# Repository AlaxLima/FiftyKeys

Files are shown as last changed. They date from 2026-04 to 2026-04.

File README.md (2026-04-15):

# FiftyKeys
A personal documentation of my from-scratch handwired 50-key keyboard design.

FiftyKeys

This project has been done back in **May 2025**. However, I have made the decision to publish this project as of April 2026.
The name FiftyKeys was chosen because this keyboard has exactly 50 keys, which had several design choices in mind that will be described further.

#### Note about licensing: 
This project is only for personal showcase, and is licensed under the [Creative Commons BY-NC-ND 4.0 License](https://github.com/AlaxLima/FiftyKeys/blob/main/LICENSE.txt).

Commercial use and redistribution of modified or works are strictly prohibited. See usage terms below for details.

### A personal goal achieved for this project
FiftyKeys does not use flashed **QMK** firmware. Yes, this keyboard is **fully programmed using Arduino C++**, and still mimics features like scanning speed adjustment, layer switching, macro mapping.

## Keyboard layout
Originally, I have decided to design a true minimal 40% layout, which only features the alpha cluster and several basic modifiers on the bottom row. However, after a while using a replica of an open-source project that featured such layout - the [Tanuki 40%](https://github.com/SethSenpai/Tanuki) by [SethSenpai](https://github.com/SethSenpai), the heavy use of layer shifting key combos eventually showed its constraints from a person who came from 65% boards.
Therefore, to maintain the minimalism of not having the number row, but keep certain areas reachable, the standard layout of this keyboard adopted:
- A standard 6.25U spacebar
- [HKKB](https://happyhackingkb.com/)-style bottom corners
- Fully accessible arrow cluster
- Delete key next to Enter/Backspace (Inspired by the Filco Majestouch Minila Air) (image different from personal adjustments)
- 3 modifers of Win, Ctrl and Shift all present
- Play/Pause media key

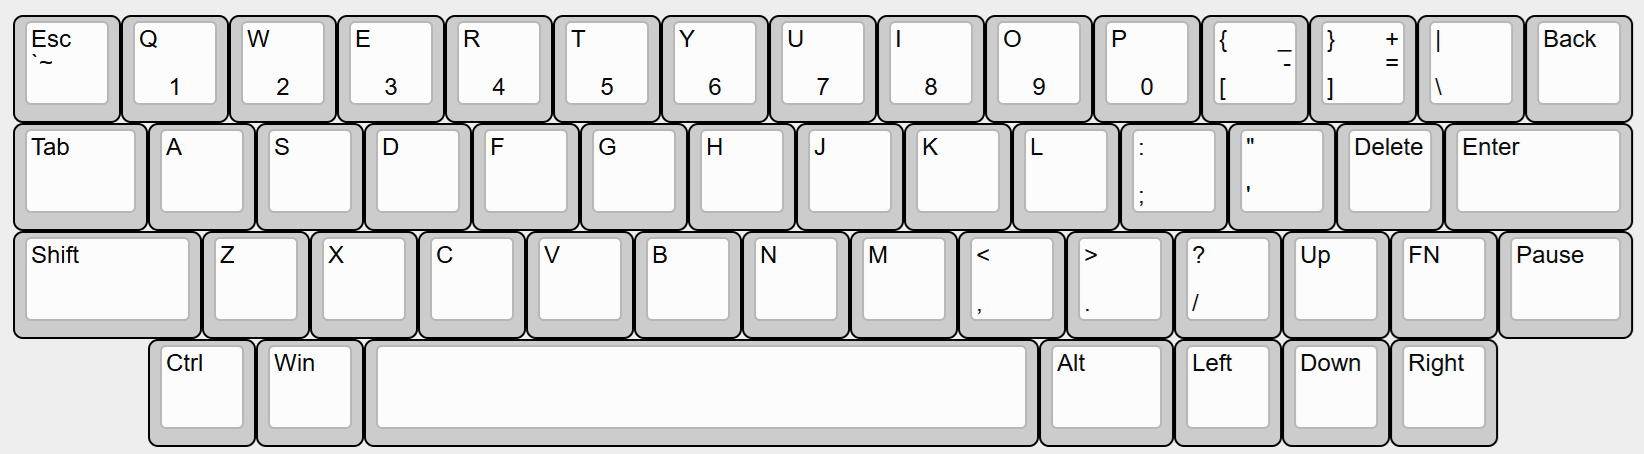
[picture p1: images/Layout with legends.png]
Layout


## Case and matrix design

### Plate and Case

While sandwich-design boards are easier and simpler to design, having a solid piece of plastic bottom case and a thick top bezel is my personal preference. Therefore, based on the original key size from KLE, further perimeter is added to work on the bezel and screw holes (via QCAD and FreeCAD).

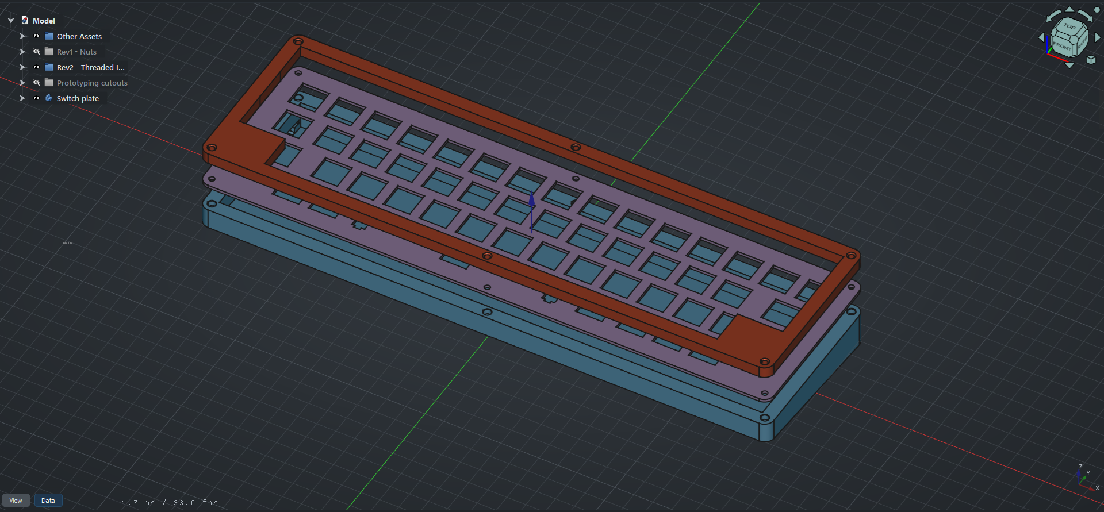
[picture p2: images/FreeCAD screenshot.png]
FreeCAD screenshot


Even though the plate is also modelled here, it is meant for a lasercutting for a 1.5mm aluminium plate (or Inox/Steel, any sheet metal material that can provide adequate rigidity).
Assembly uses M3 heat-threaded inserts inside the 3D printed bottom case, and installed with countersunk M3 screws

### Matrix circuitry

Like many other handwired projects, FiftyKeys uses an Arduino Pro Micro on a handwired matrix. On this matrix, all rows and columns are mapped out from A to F and 1 to 9, which later corresponds to the pins on the microcontroller. The rows are chained with 1N4148 diodes (basic anti-ghosting component for keyboards), while gauge wire are used for columns, and further soft wires to the microcontroller.

Handrawn matrix to reference to during solder, keymapping and pin mapping in code:
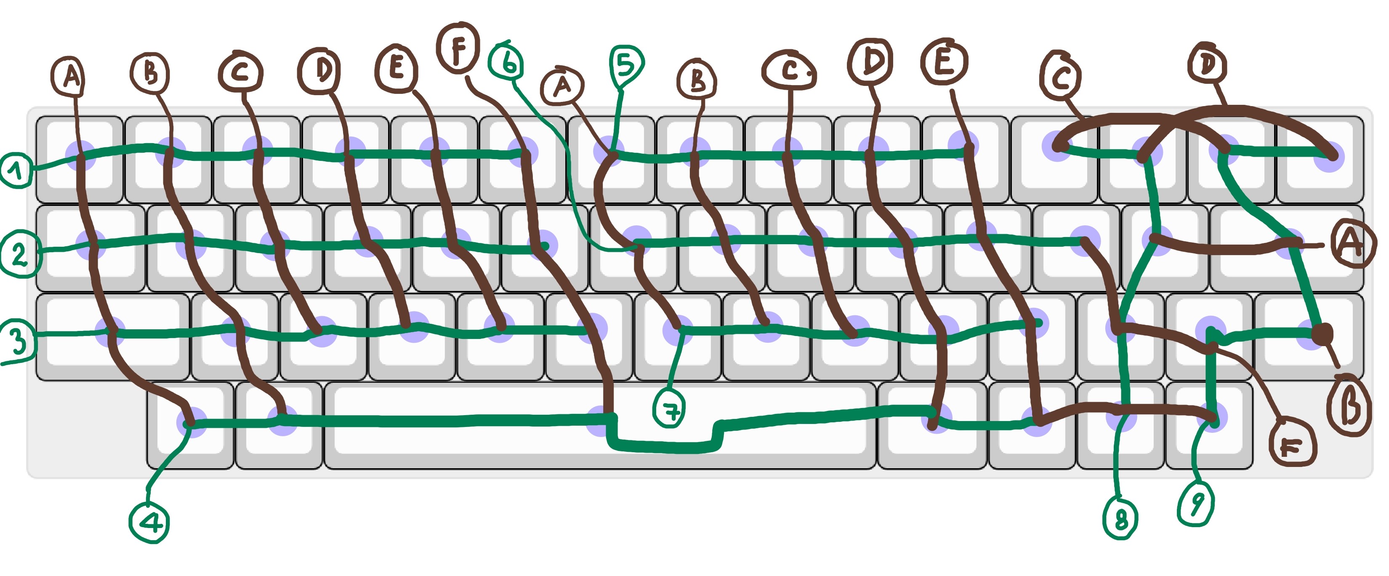
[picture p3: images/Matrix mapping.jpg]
Matrix mapping


Since I do not have SMD solder experience, I had to use a pin breakout board instead for a pigtail cable. Therefore, the acoustic foam mod for the keyboard requires a cutout solely for the bulky part of the microcontroller and the pigtail board itself. In addition, the Elaina sticker is in the center to prevent the microcontroller's flashing light getting through the PETG plastic's 3D print.

Interior1 image

### Arduino code

This project's personally hardest part lies in the big number one goal at the start: It needs to be an entire code structure that at least does certain basic things that QMK does out of the box. However, another personal wanting was made during back during the making: To intentionally add a certain level of modularity to the code so that it can later be easily fixed, or reused for any future personal projects (which is clearly a low likelihood).

There is a sheer amount of repetitiveness and certain choices made that could have been improved (which gave birth to the idea of a .h file to focus more on the complex part instead of the repetitive part), but any further development was stopped to prevent personal scope creep.

If you would like to view the code and understand further how it works, the [.ino code file](https://github.com/AlaxLima/FiftyKeys/blob/main/code/FiftyKeys_Firmware.ino) and its [lookup .h file](https://github.com/AlaxLima/FiftyKeys/blob/main/code/KeyLookupSwitch.h) is available in this repository. A snippet of temporary troubleshooter code was also included, which you can see it as a snapshot of my work half-done during then.

Still, to have a brief showcase, here is a TL;DR tree structure simplified using my own language:

```
Keyboard codebase (.ino file, uploaded via Arduino IDE)
├── Keymapping
│   └── Which key to map on all keys in every layer
├── Direct Port Control macro setup
│   └── Simplify all port manipulation codes into functions
├── Timer1 Interrupt
│   └── Initial setup
├── void setup()
│   └── Arduino configuration for pins and libraries
├── Matrix reading
│   ├── Logic to read through columns per driven row
│   │   ├── Keycode lookup (keycode, keytype and layer)
│   │   └── Press and release management
│   └── Logic loop
├── Sleep mechanism
│   ├── Secondary tick for sleep modes
│   └── Adjust Timer1 by sleep status
└── Macro Engine
    └── MacroMap interpreter
Offset file (.h file, included inside the codebase)
├── Filter between macro/consumer/keyboard keys and press/release state
│   ├── Keyboard.h keys lookup
│   ├── Consumer.h keys lookup
│   └── Macro keys lookup
└── Macro array configuration
```

### Usage terms regarding license restrictions

This project and documentation is made as a personal showcase of my own work in keyboard design and microcontroller code development. It is open to non-commercial use, which includes:
- Reference, learning from the code and design
- Create personal replicas
However, the following uses are not permitted:
- Commercial use or production of any of the project's material
- Redistribution of derivative or modified works
- Use any material in this project in other projects intended for distribution
- Reposting/republishing of any content from this repository elsewhere

Re-implementation is allowed, however it must not be direct use of any assets. Feel free to contact me for any use beyond these terms.

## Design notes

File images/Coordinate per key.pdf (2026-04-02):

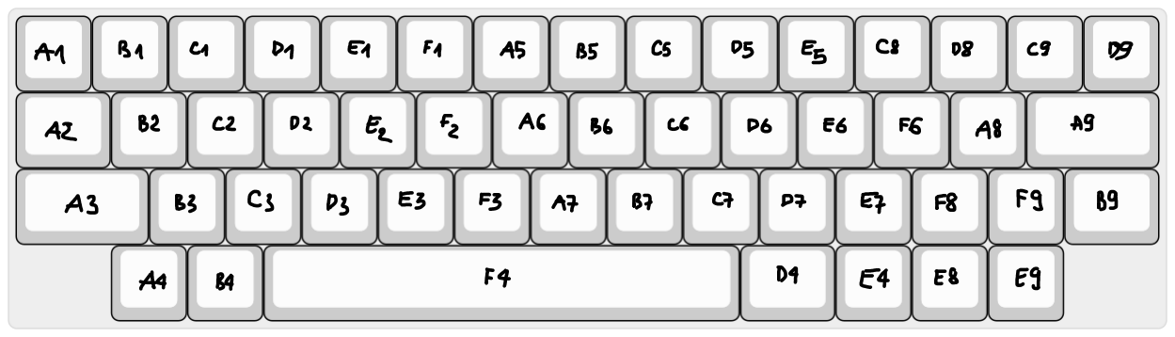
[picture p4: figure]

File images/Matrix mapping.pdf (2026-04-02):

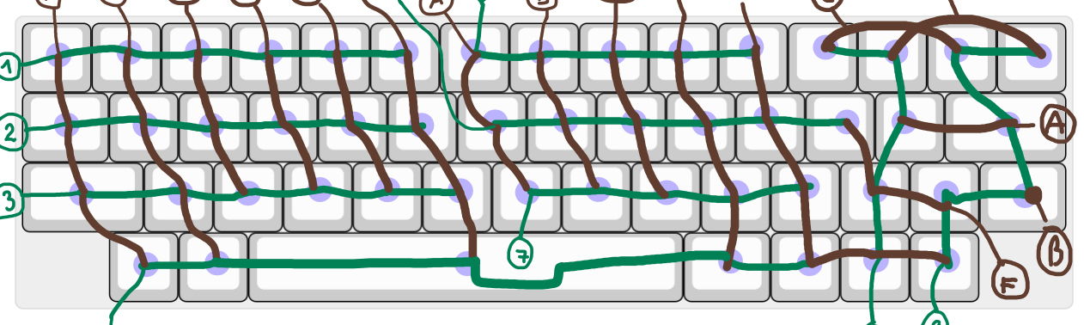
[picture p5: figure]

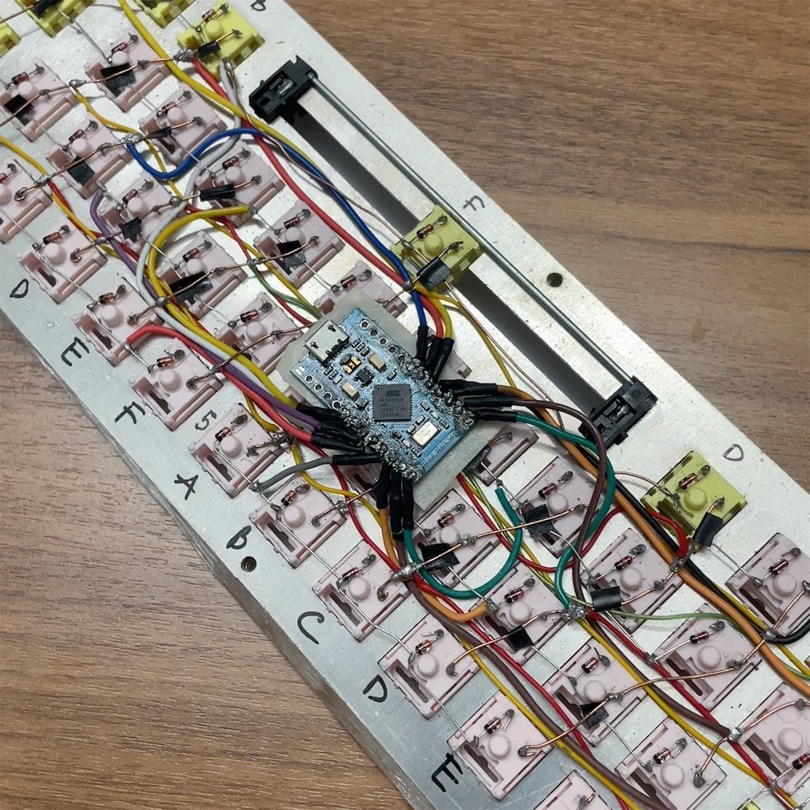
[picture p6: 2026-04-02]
images/Interior2.png

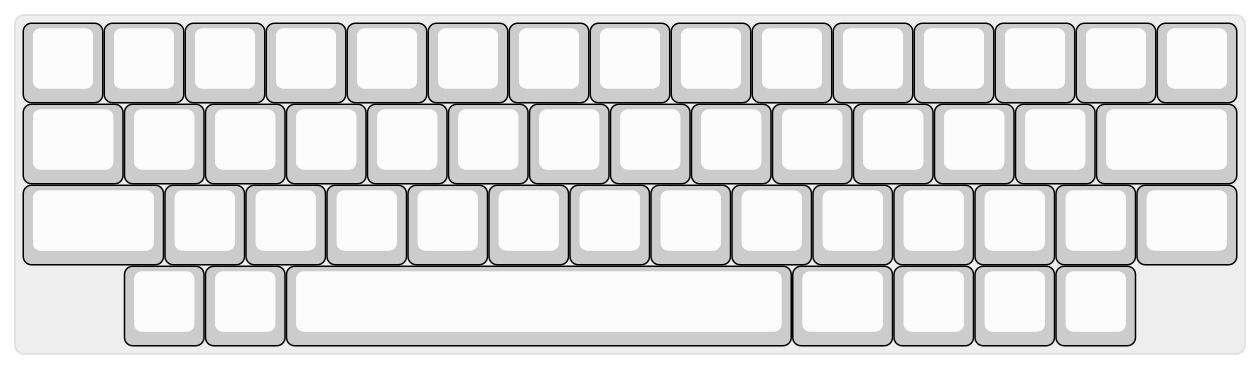
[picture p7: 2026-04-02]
images/Layout blank.png

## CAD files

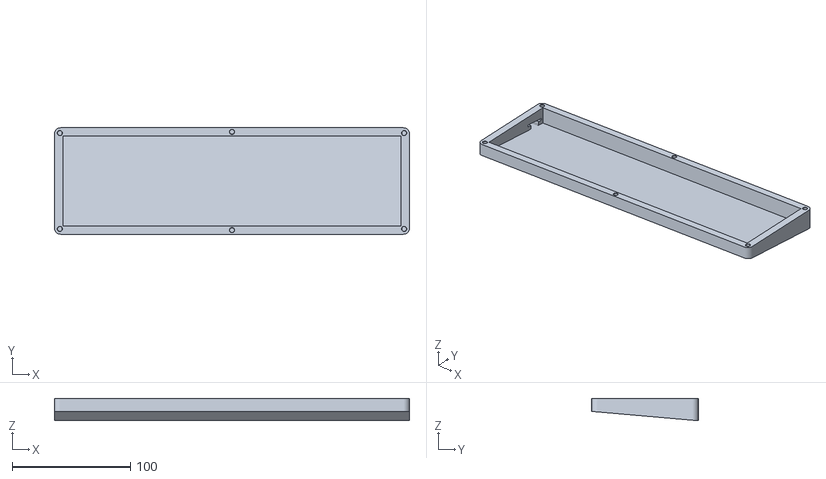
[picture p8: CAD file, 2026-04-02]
designs/FiftyKeys-Case.stl
300.0 x 90.0 x 19.0

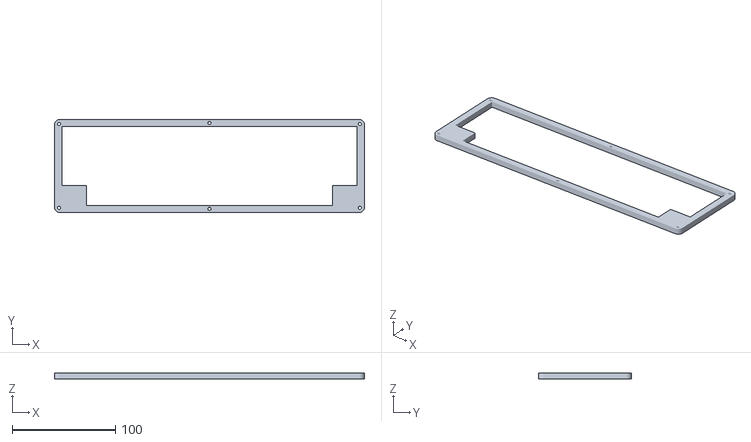
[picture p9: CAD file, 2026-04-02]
designs/FiftyKeys-Bezel.stl
300.0 x 90.0 x 6.00

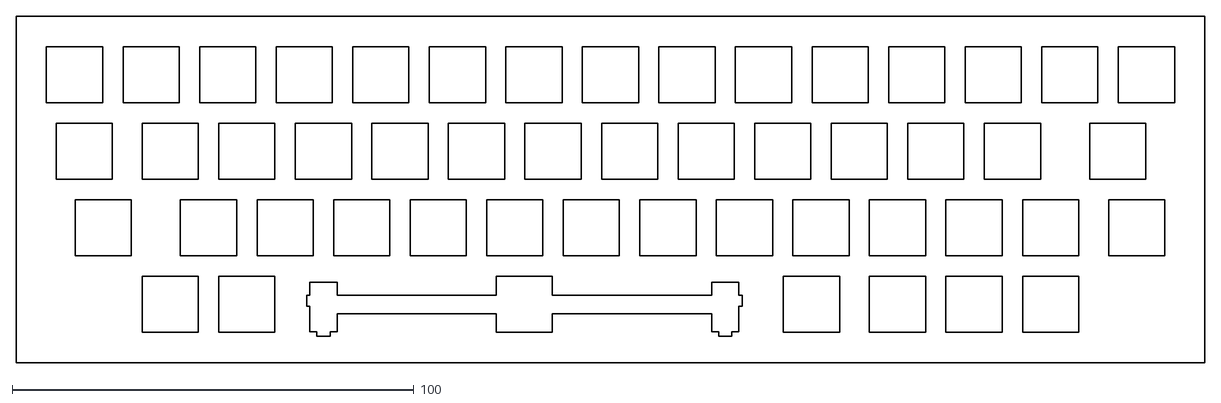
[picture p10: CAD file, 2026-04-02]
designs/Keebio Plate Gen export from KLE.dxf
295.7 x 86.2

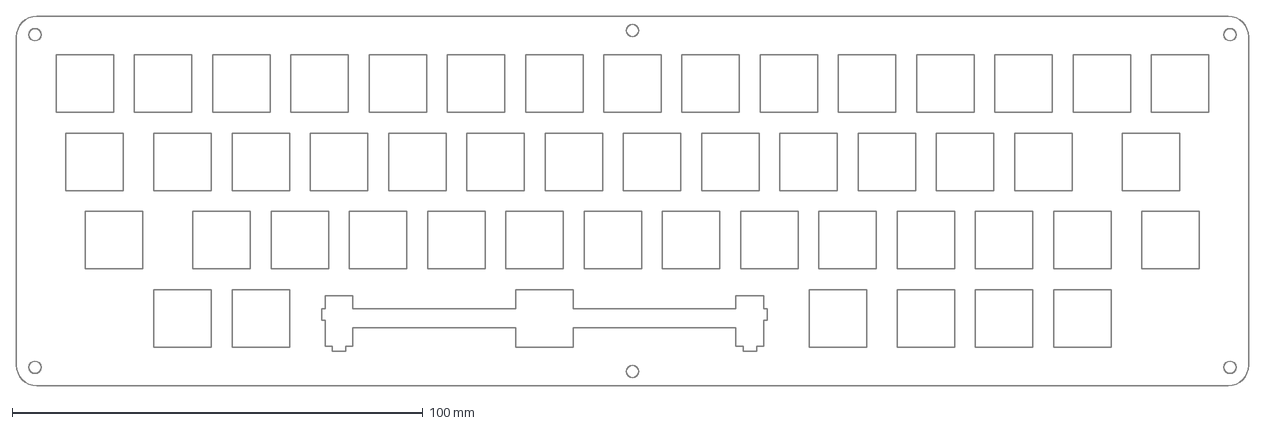
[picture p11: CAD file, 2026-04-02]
designs/Keyplate - lasercut ver.dxf
300.0 x 90.0 mm

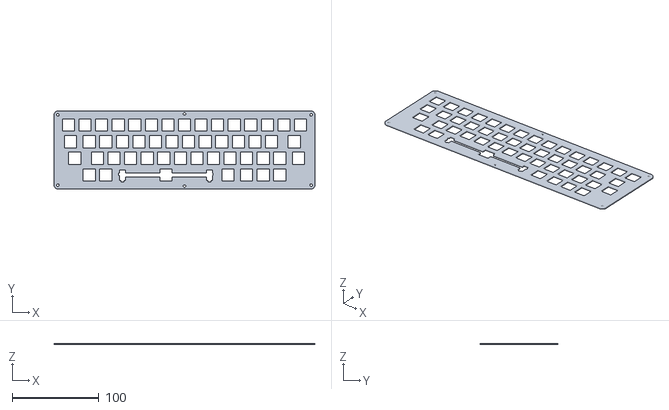
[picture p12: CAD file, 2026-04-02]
designs/FiftyKeys-Plate.stl
300.0 x 90.0 x 1.60

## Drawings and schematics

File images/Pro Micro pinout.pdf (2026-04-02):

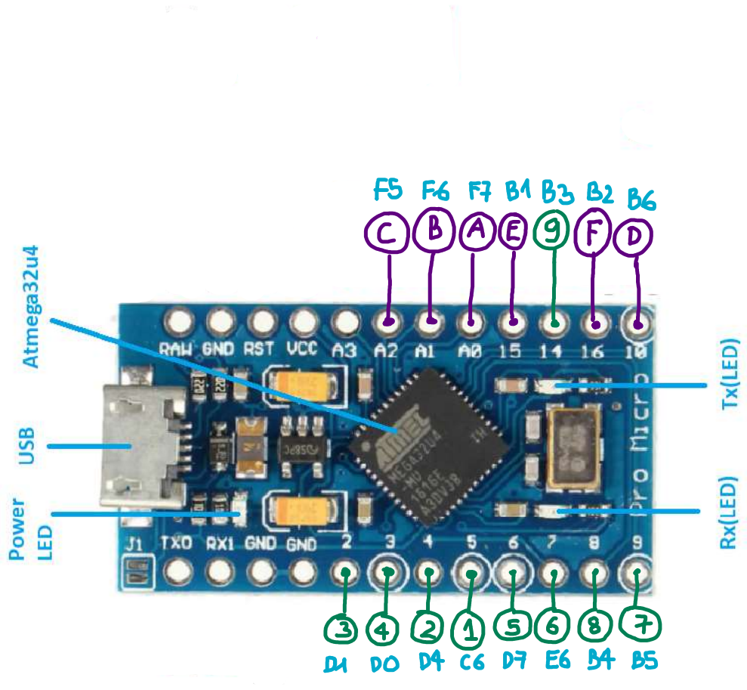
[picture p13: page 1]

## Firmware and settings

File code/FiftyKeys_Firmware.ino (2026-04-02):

#include <HID-Project.h>
#include <HID-Settings.h>

#include "KeyLookupSwitch.h"
// #include "BoardConf.h"

/*
// 2 parallel arrays in flash
#define ENTRY(name, code) const char name##_str[] PROGMEM = #name;
KEY_LIST
#undef ENTRY

struct KeyPair { const char* str; uint8_t code; };

#define ENTRY(name, code) { name##_str, code },
const KeyPair keyTable[] PROGMEM = {
  KEY_LIST
};
#undef ENTRY


// Runtime string converter
const uint8_t keyCount = sizeof(keyTable) / sizeof(keyTable[0]);

uint8_t resolveKey(const char* alias) {
  for (uint8_t i = 0; i < keyCount; i++) {
    const char* p = (const char*)pgm_read_ptr(&keyTable[i].str);
    if (strcmp_P(alias, p) == 0) {
      return pgm_read_byte(&keyTable[i].code);
    }
  }
  return 0;                // fall-back “no key”
}
*/

// #define NO_KEY 0x00 // KEY_RESERVED is a predefined option instead of this
const uint8_t KEY_FUNCTION = 255; // Custom FN key to be used for other purposes, max value of uint8_t is 255
const uint8_t KEY_REMAPPED_LEFT_ALT = 50;

const uint8_t MACRO_01 = 235;
const uint8_t MACRO_02 = 236;
const uint8_t MACRO_03 = 237;
const uint8_t MACRO_04 = 238;
const uint8_t MACRO_05 = 239;
const uint8_t MACRO_06 = 240;
const uint8_t MACRO_07 = 241;
const uint8_t MACRO_08 = 242;
const uint8_t MACRO_09 = 243;
const uint8_t MACRO_10 = 244;

const uint8_t layerCount = 2;
const uint8_t rowCount = 9;
const uint8_t columnCount = 6;

bool keyStates[rowCount][columnCount] = {false}; // Row-major key state matrix

const uint8_t KeyMap[layerCount][rowCount][columnCount] = {
    {{KEY_ESC, KEY_Q, KEY_W, KEY_E, KEY_R, KEY_T},
     {KEY_TAB, KEY_A, KEY_S, KEY_D, KEY_F, KEY_G},
     {KEY_LEFT_SHIFT, KEY_Z, KEY_X, KEY_C, KEY_V, KEY_B},
     {KEY_LEFT_CTRL, KEY_LEFT_GUI, KEY_RESERVED, KEY_REMAPPED_LEFT_ALT, KEY_LEFT_ARROW, KEY_SPACE},
     {KEY_Y, KEY_U, KEY_I, KEY_O, KEY_P, KEY_RESERVED},
     {KEY_H, KEY_J, KEY_K, KEY_L, KEY_SEMICOLON, KEY_QUOTE},
     {KEY_N, KEY_M, KEY_COMMA, KEY_PERIOD, KEY_SLASH, KEY_RESERVED},
     {KEY_BACKSLASH, KEY_RESERVED, KEY_LEFT_BRACE, KEY_RIGHT_BRACE, KEY_DOWN_ARROW, KEY_UP_ARROW},
     {KEY_ENTER, MEDIA_PLAY_PAUSE, KEY_BACKSPACE, KEY_DELETE, KEY_RIGHT_ARROW, KEY_FUNCTION}},
    {{KEY_TILDE, KEY_1, KEY_2, KEY_3, KEY_4, KEY_5},
     {KEY_CAPS_LOCK, KEY_F1, KEY_F3, KEY_F5, KEY_F7, KEY_F9},
     {KEY_LEFT_SHIFT, KEY_F2, KEY_F4, KEY_F6, KEY_F8, KEY_F10},
     {KEY_LEFT_CTRL, KEY_LEFT_GUI, KEY_RESERVED, KEY_RIGHT_ALT, MEDIA_PREVIOUS, MEDIA_VOLUME_MUTE},
     {KEY_6, KEY_7, KEY_8, KEY_9, KEY_0, KEY_RESERVED},
     {KEY_F11, KEY_RESERVED, KEY_RESERVED, MACRO_03, MACRO_05, MACRO_06},
     {KEY_F12, MACRO_02, CONSUMER_BRIGHTNESS_DOWN, CONSUMER_BRIGHTNESS_UP, KEY_INSERT, KEY_RESERVED},
     {KEY_DELETE, KEY_RESERVED, KEY_MINUS, KEY_EQUAL, MEDIA_VOLUME_DOWN, MEDIA_VOLUME_UP},
     {KEY_ENTER, MEDIA_VOLUME_MUTE, KEY_RESERVED, MACRO_04, MEDIA_NEXT, KEY_FUNCTION}}};

/*
const uint8_t L1KeyMapRow0[6] = {KEY_ESC, KEY_Q, KEY_W, KEY_E, KEY_R, KEY_T};
const uint8_t L1KeyMapRow1[6] = {KEY_TAB, KEY_A, KEY_S, KEY_D, KEY_F, KEY_G};
const uint8_t L1KeyMapRow2[6] = {KEY_LEFT_SHIFT, KEY_Z, KEY_X, KEY_C, KEY_V, KEY_B};
const uint8_t L1KeyMapRow3[6] = {KEY_LEFT_CTRL, KEY_LEFT_GUI, KEY_RESERVED, KEY_RIGHT_ALT, KEY_LEFT_ARROW, KEY_SPACE};
const uint8_t L1KeyMapRow4[6] = {KEY_Y, KEY_U, KEY_I, KEY_O, KEY_P, KEY_RESERVED};
const uint8_t L1KeyMapRow5[6] = {KEY_H, KEY_J, KEY_K, KEY_L, KEY_SEMICOLON, KEY_QUOTE};
const uint8_t L1KeyMapRow6[6] = {KEY_N, KEY_M, KEY_COMMA, KEY_PERIOD, KEY_SLASH, KEY_RESERVED};
const uint8_t L1KeyMapRow7[6] = {KEY_DELETE, KEY_RESERVED, KEY_LEFT_BRACE, KEY_RIGHT_BRACE, KEY_DOWN_ARROW, KEY_UP_ARROW};
const uint8_t L1KeyMapRow8[6] = {KEY_ENTER, MEDIA_PLAY_PAUSE, KEY_BACKSPACE, KEY_BACKSLASH, KEY_RIGHT_ARROW, KEY_FUNCTION};

const uint8_t *L1KeyMap[9] = {
    L1KeyMapRow0,
    L1KeyMapRow1,
    L1KeyMapRow2,
    L1KeyMapRow3,
    L1KeyMapRow4,
    L1KeyMapRow5,
    L1KeyMapRow6,
    L1KeyMapRow7,
    L1KeyMapRow8,
};
*/

uint8_t layer = 0; // For global FN key, overwrite capability
bool activeFlag = 1;

// -- Macros for Direct Port Control --

// Predessor macros that did not worked with the arrays
// #define DirectHIGH(port, pin) (PORT##port |= (1 << pin))
// #define DirectLOW(port, pin) ((PORT##port) &= ~(1 << (pin)))

// This is more likely preferred
#define SetLow(reg, bit) (*(reg) &= ~(1 << (bit)))
#define SetHigh(reg, bit) (*(reg) |= (1 << (bit)))

// One inline macro
// Active-low because INPUT_PULLUP
#define PullupRead(idx) (!(*(colPortRegs[idx]) & _BV(colBits[idx])))

// Keyboard pinout
// Direct port:       C6 D4 D1 D0 D7 E6 B5 B4 B1
uint8_t rowPins[9] = {5, 4, 2, 3, 6, 7, 9, 8, 14};
uint8_t colPins[6] = {A0, A1, A2, 10, 15, 16};

// Row pin port pointers
volatile uint8_t *const rowPortRegs[9] = {
    &PORTC, &PORTD, &PORTD, &PORTD, &PORTD, &PORTE, &PORTB, &PORTB, &PORTB};
const uint8_t rowBits[9] = {6, 4, 1, 0, 7, 6, 5, 4, 3};

volatile uint8_t *const colPortRegs[6] = {
    &PINF, &PINF, &PINF, &PINB, &PINB, &PINB};
const uint8_t colBits[6] = {7, 6, 5, 6, 1, 2};

// TimerInterrupt initalize
void initialTimer1()
{
    cli(); // Disable interrupts
    TCCR1A = 0;
    TCCR1B = 0;
    TCCR1B |= (1 << WGM12);              // CTC mode
    TCCR1B |= (1 << CS11) | (1 << CS10); // Prescaler 64
    OCR1A = 999;                         // (16MHz / 64 / Hz) - 1
    TIMSK1 |= (1 << OCIE1A);             // Enable compare interrupt

    // !!!! DO NOT DELETE OR BOARD WILL CORRUPT !!!!
    sei(); // Enable interrupts
}

void setup()
{
    // Initialize ISR modules
    initialTimer1();

    Serial.begin(9600);

    // Rows initialization
    for (int r = 0; r < 9; r++)
    {
        pinMode(rowPins[r], OUTPUT);
        digitalWrite(rowPins[r], HIGH);
    }

    // Columns initialization
    for (int c = 0; c < 6; c++)
    {
        pinMode(colPins[c], INPUT_PULLUP);
        // digitalWrite(colPins[c], HIGH); //No need for conventional pinMode declaration
    }
    // Keyboard.begin();
    Consumer.begin();
    // currentLayer = 1;
}

void coordinateDiagnostics(bool keyState, uint8_t outputRow, uint8_t outputCol, uint8_t outputKeycode)
{
    switch (keyState)
    {
    case 1:
        Serial.println("");
        Serial.println("[PRESSING]");
        Serial.print("Row ");
        Serial.print(outputRow);
        Serial.print(" column ");
        Serial.print(outputCol);
        Serial.print(" - Keycode ");
        Serial.println(outputKeycode);
        break;
    case 0:
        Serial.println("");
        Serial.println("[RELEASING]");
        Serial.print("Row ");
        Serial.print(outputRow);
        Serial.print(" column ");
        Serial.print(outputCol);
        Serial.print(" - Keycode ");
        Serial.println(outputKeycode);
        break;
    }
}

uint8_t layerSwitch(uint8_t keycode)
{
    switch (keycode)
    {
    case 255:
        return 2;
        break;
    default:
        return 1;
        break;
    }
}
/*
void readingRow0()
{
    for (int c = 0; c < 6; c++)
    {
        bool colRead = PullupRead(c); // = 1 when pressed
        // const char *alias = L1KeyMapRow1[c];
        // uint8_t code = resolveKey(alias);

        if (colRead && !keyStates[0][c]) // was not pressed before
        {
            keyStates[0][c] = true;
            keyTypeLookup(1, L1KeyMap[0][c]);
            coordinateDiagnostics(keyStates[0][c], 0, c, L1KeyMap[0][c]);
        }
        else if (!colRead && keyStates[0][c]) // was pressed, now released
        {
            keyTypeLookup(0, L1KeyMap[0][c]);
            keyStates[0][c] = false;
            coordinateDiagnostics(keyStates[0][c], 0, c, L1KeyMap[0][c]);
        }
    }
}
*/

/*
void readingRows(uint8_t row) // First try
{
    for (int c = 0; c < 6; c++)
    {
        bool colRead = PullupRead(c); // = 1 when pressed
        // const char *alias = L1KeyMapRow1[c];
        // uint8_t code = resolveKey(alias);

        if (colRead && !keyStates[row][c]) // was not pressed before
        {
            keyStates[row][c] = true;
            keyTypeLookup(1, L1KeyMap[row][c]);
            coordinateDiagnostics(keyStates[row][c], 0, c, L1KeyMap[row][c]);
        }
        else if (!colRead && keyStates[row][c]) // was pressed, now released
        {
            keyTypeLookup(0, L1KeyMap[row][c]);
            coordinateDiagnostics(keyStates[row][c], 1, c, L1KeyMap[row][c]);
            break;
            keyStates[row][c] = false;
        }
    }
}
*/

void readingRows(uint8_t row)
{
    for (int col = 0; col < columnCount; col++)
    {
        bool colRead = PullupRead(col); // active low
        uint8_t key = KeyMap[layer][row][col];

        if (key == KEY_RESERVED)
            continue;

        if (colRead && !keyStates[row][col])
        {
            keyStates[row][col] = true;
            activeFlag = 1;

            if (key == KEY_FUNCTION)
            {
                layer = 1;
                Keyboard.releaseAll();
            }
            else if (isMacroKeycode(key))
            {
                MacroRun(key);
            }
            else
            {
                keyTypeLookup(1, key);
            }
            // coordinateDiagnostics(keyStates[row][col], row, col, key);
        }
        else if (!colRead && keyStates[row][col])
        {
            keyStates[row][col] = false;
            activeFlag = 0;

            if (key == KEY_FUNCTION)
            {
                layer = 0;
                Keyboard.releaseAll();
            }
            else if (!isMacroKeycode(key)) // Don't "release" macro
            {
                keyTypeLookup(0, key);
            }
            // coordinateDiagnostics(keyStates[row][col], row, col, key);
        }
    }
}

// Column reading
void chosenReadingRow(uint8_t activeRow)
{
    /*
    switch (activeRow)
    {
    case 0:
        readingRows(0);
        break;
    case 1:
        readingRows(1);
        break;
    case 2:
        readingRows(2);
        break;
    case 3:
        readingRows(3);
        break;
    case 4:
        readingRows(4);
        break;
    case 5:
        readingRows(5);
        break;
    case 6:
        readingRows(6);
        break;
    case 7:
        readingRows(7);
        break;
    case 8:
        readingRows(activeRow);
        break;
    }
    */
    readingRows(activeRow);

    /*

    for (int c = 0; c < 6; c++)
    {
        bool colRead = PullupRead(c); // true = key is pressed

        // const char *alias = L1KeyMapRow1[c];
        // uint8_t code = resolveKey(alias);

        if (colRead && !keyStates[0][c]) // was not pressed before
        {
            //Keyboard.press(code); // replace with your key map later
            keyStates[activeRow][c] = true;
            keyborePress(L1KeyMap[activeRow][c]);
            Serial.print("Pressed row ");
            Serial.print(activeRow);
            Serial.print(" column ");
            Serial.println(c);
        }
        else if (!colRead && keyStates[0][c]) // was pressed, now released
        {
            keyboreRelease(L1KeyMap[activeRow][c]);
            keyStates[activeRow][c] = false;
            Serial.print("Released row ");
            Serial.print(activeRow);
            Serial.print(" column ");
            Serial.println(c);
            Serial.print("Key code is ");
            Serial.println(L1KeyMap[activeRow][c]);
        }
    }
    */
}

inline void driveRow(uint8_t activeRow)
{
    for (uint8_t r = 0; r < 9; r++)
    {
        if (r == activeRow)
            SetLow(rowPortRegs[r], rowBits[r]); // selected row LOW
        else
            SetHigh(rowPortRegs[r], rowBits[r]); // others HIGH
    }
}

ISR(TIMER1_COMPA_vect)
{
    static uint8_t row = 0;
    driveRow(row); // set the lines
    // chosenReadingRow(row); // read ONLY ONCE
    readingRows(row);
    row = (row + 1) % 9; // next row next tick
}

/* ─── VOID LOOP USED FOR IDLING COUNT ─── */
void adjustTimer1(int status, uint16_t OCR1A_tickrate)
{
    switch (status)
    {
    case -1:
        cli(); // Disable interrupts
        TCCR1B |= (1 << CS11) | (1 << CS10);
        TIMSK1 |= (1 << OCIE1A);
        OCR1A = OCR1A_tickrate;
        sei(); // Enable interrupts
        break;
    case 1:
        cli();
        OCR1A = OCR1A_tickrate;
        TCCR1B &= ~(1 << CS10); // Clear CS10
        TCCR1B &= ~(1 << CS11); // Clear CS11
        TCCR1B &= ~(1 << CS12); // Clear CS12
        TIMSK1 &= ~(1 << OCIE1A);
        sei();
        break;
    case 0:
        cli();
        OCR1A = OCR1A_tickrate;
        sei();
        break;
    }

    /*
    Adjustments:
    - Shutdown:     1 + 62499
    - Startup:      -1 + ACTIVE mode value
    - Change:       0 + IDLE mode value
    */
}

const uint16_t SLEEP_TIMEOUT = 100;

uint8_t ACTIVE_RATE = 499;
uint8_t SLEEP_RATE = 62499; // No need anyway

bool sleepLock = 0;
bool openAllRows = 0;

void loop()
{
    while (!sleepLock)
    {
        for (uint16_t t = 0; t < SLEEP_TIMEOUT + 1; t++)
        {
            if (activeFlag)
            {
                // Serial.println("Hewoo :3");
                // adjustTimer1(0, ACTIVE_RATE);
                break;
            }
            switch (t)
            {
            case SLEEP_TIMEOUT:
                adjustTimer1(1, SLEEP_RATE);
                Serial.println("--zzz--zzz-");
                sleepLock = 1;
                openAllRows = 1;
            default:
                break;
            }
            // Serial.println();
            delay(100);
        }
    }
    while (sleepLock)
    {
        if (openAllRows)
        {
            for (uint8_t r = 0; r < rowCount; r++)
            {
                SetLow(rowPortRegs[r], rowBits[r]);
            }
            openAllRows = 0;
        }
        uint8_t sumCol = PullupRead(0) + PullupRead(1) + PullupRead(2) + PullupRead(3) + PullupRead(4) + PullupRead(5);
        if (sumCol > 0)
        {
            adjustTimer1(-1, ACTIVE_RATE);
            Serial.println("Good meowning~ nya~ :3");
            activeFlag = 1;
            sleepLock = 0; // Wake the board up
            break;
        }
        delay(50);
    }
}

/* ─── STORAGE AND MEMORY TRACKING ─── */
// update 1     (built a repetitive structure)      : 5142B     space, 246B mem
// update 2     (w/ direct port macros)             : 5392B     space, 273B mem
// update 3     (added ISR timer1 scan loop)        : 6112B     space, 313B mem
// update 4     (done scan, column switch)          : 7352B     space, 363B mem
// update 6     (Keymap swapped char* w/ uint8_t)   : 7192B     space, 407B mem
// update 7     (L1 finished, .h lookup file)       : 11960B    space, 495B mem
// Update 8     (Keymap on 3D array)                : 12054B    space, 550B mem
// Update 9     (Final polishing)

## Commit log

2026-04-02 All original materials of the project uploaded
    [FiftyKeys-Bezel.stl, FiftyKeys-Case.stl, FiftyKeys-Plate.stl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]
2026-04-15 Rename firmware code to no longer be a WIP file
    [FiftyKeys_Firmware.ino]
